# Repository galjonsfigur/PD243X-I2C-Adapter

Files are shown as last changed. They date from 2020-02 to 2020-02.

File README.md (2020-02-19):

# PD243X I²C Display Adapter Board

This repository contains KiCad design files, schematics and gerber files for a simple adapter board that allows to use old PD2435, PD2436 and PD2437 dot-matrix displays with most microcontrollers using I²C protocol instead of pin-consuming  parallel interface. They can be used as neat little displays for any project that requires some kind of simple and old-looking display.

## Photo (more in `images` folder)

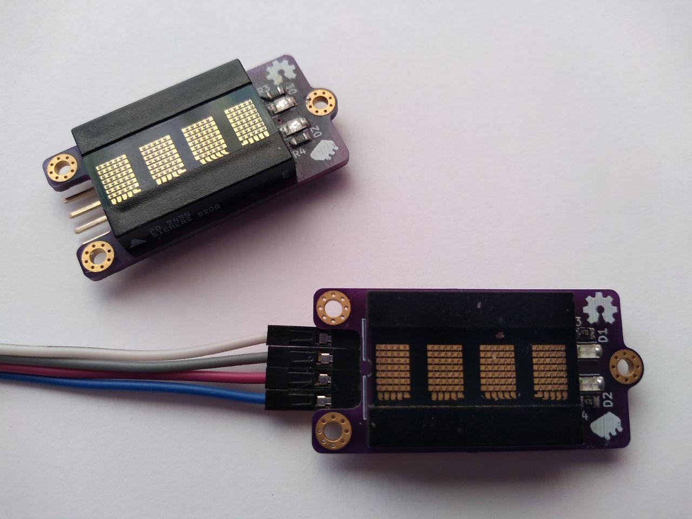
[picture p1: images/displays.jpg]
Display


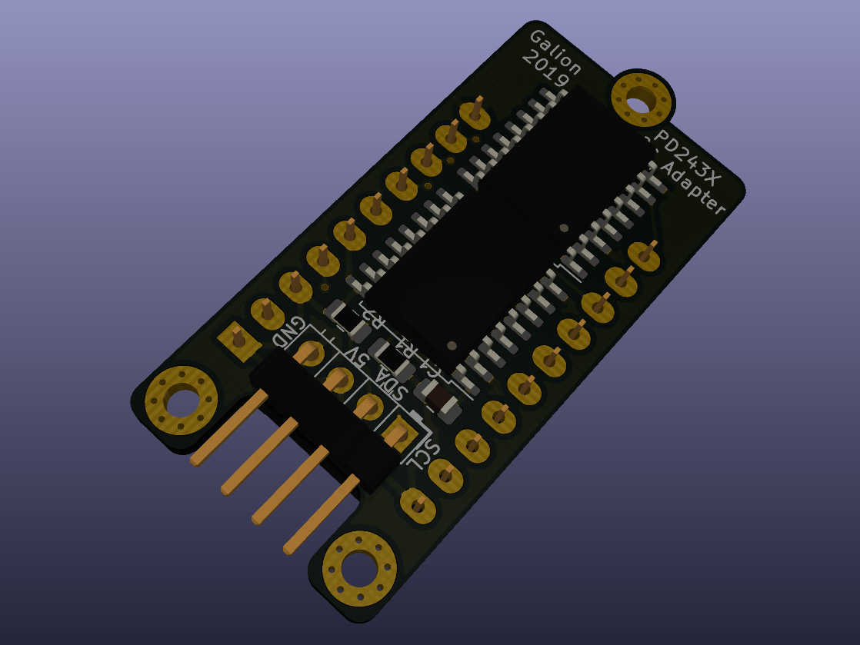
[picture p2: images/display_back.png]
3D view


## Details
PD245x displays are small four-digit alphanumeric dot-matrix displays. They use 8-bit data bus, 3-bit address line and additional signals to receive data from microcontroller. Because parallel interface requires many I/O pins to work, a simple I²C adapter board was designed. It uses 2 PCF8574T ICs to control all required pins of the display.

## Compatibility

This adapter board was designed with PD2435 in mind but it's working also with other color variants. According to the datasheet Also PD323X and PD443X displays can be used but probably they won't fit on this PCB as nicely as PD243X. 

## Bill of materials

- *1x*: PD243X display
- *1x*: 4 pin single row right angled header with 2.54mm pin spacing
- *2x*: PFC8574 I²C expander in SOIC-16 package
- *1x*: 100nF capacitor in 0805 SMD package
- *2x*: 4.7k ohm resisttor in 0805 SMD package
- *2x*: 470 ohm resisttor in 0805 SMD package
- *1x*: Green LED in 1206 SMD package
- *1x*: Red LED in 1206 SMD package

## License

[Solderpad Hardware Licence Version 2.0](LICENSE.md)

## Author
[Galion](galion$AT$sdf.org)

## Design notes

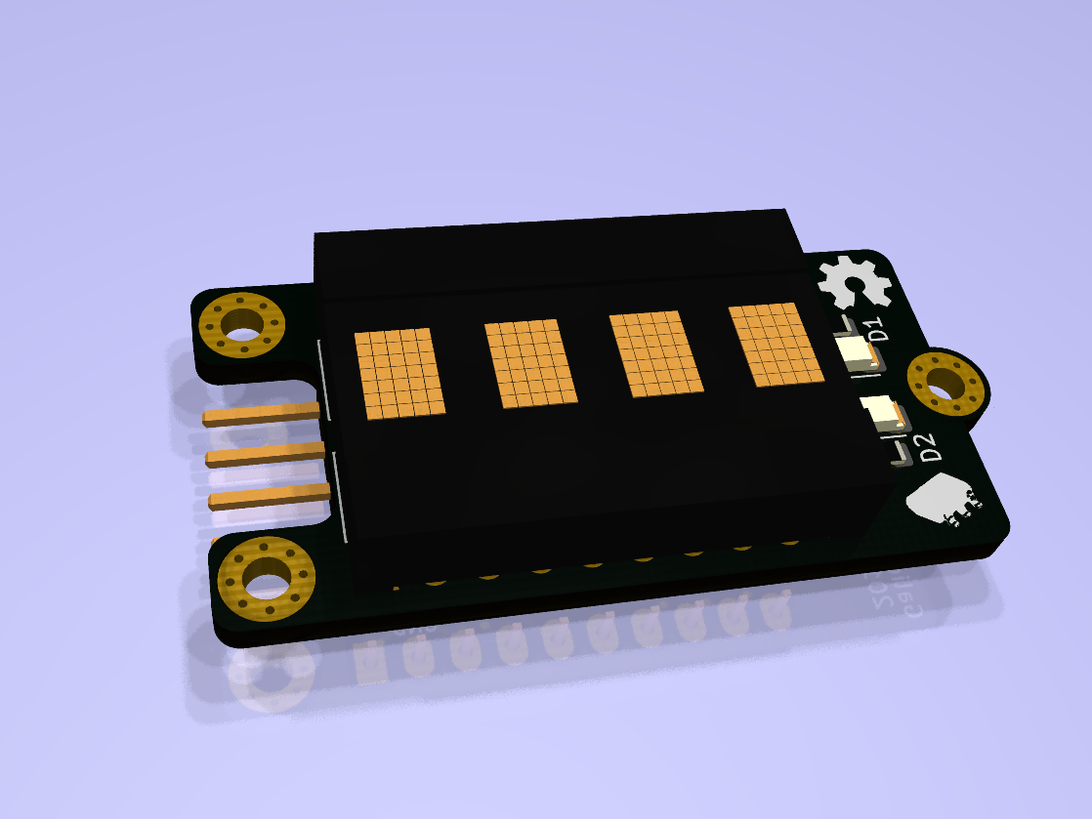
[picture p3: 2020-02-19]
images/display_front.png

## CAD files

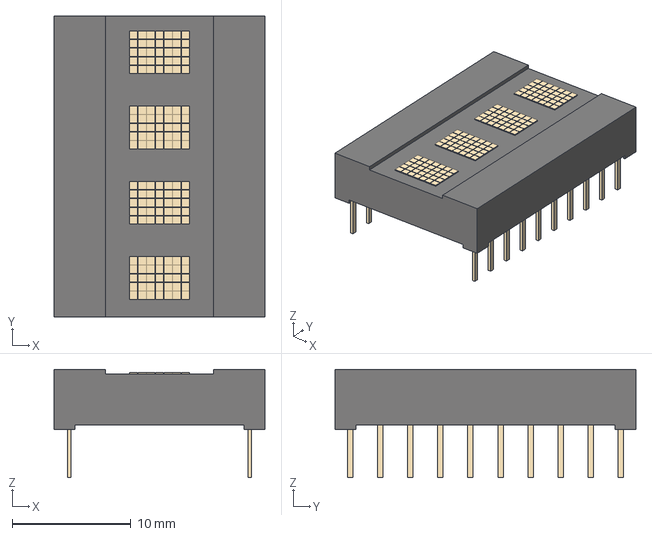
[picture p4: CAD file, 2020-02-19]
custom_symbols/PD2435.step
17.8 x 25.4 x 9.14 mm

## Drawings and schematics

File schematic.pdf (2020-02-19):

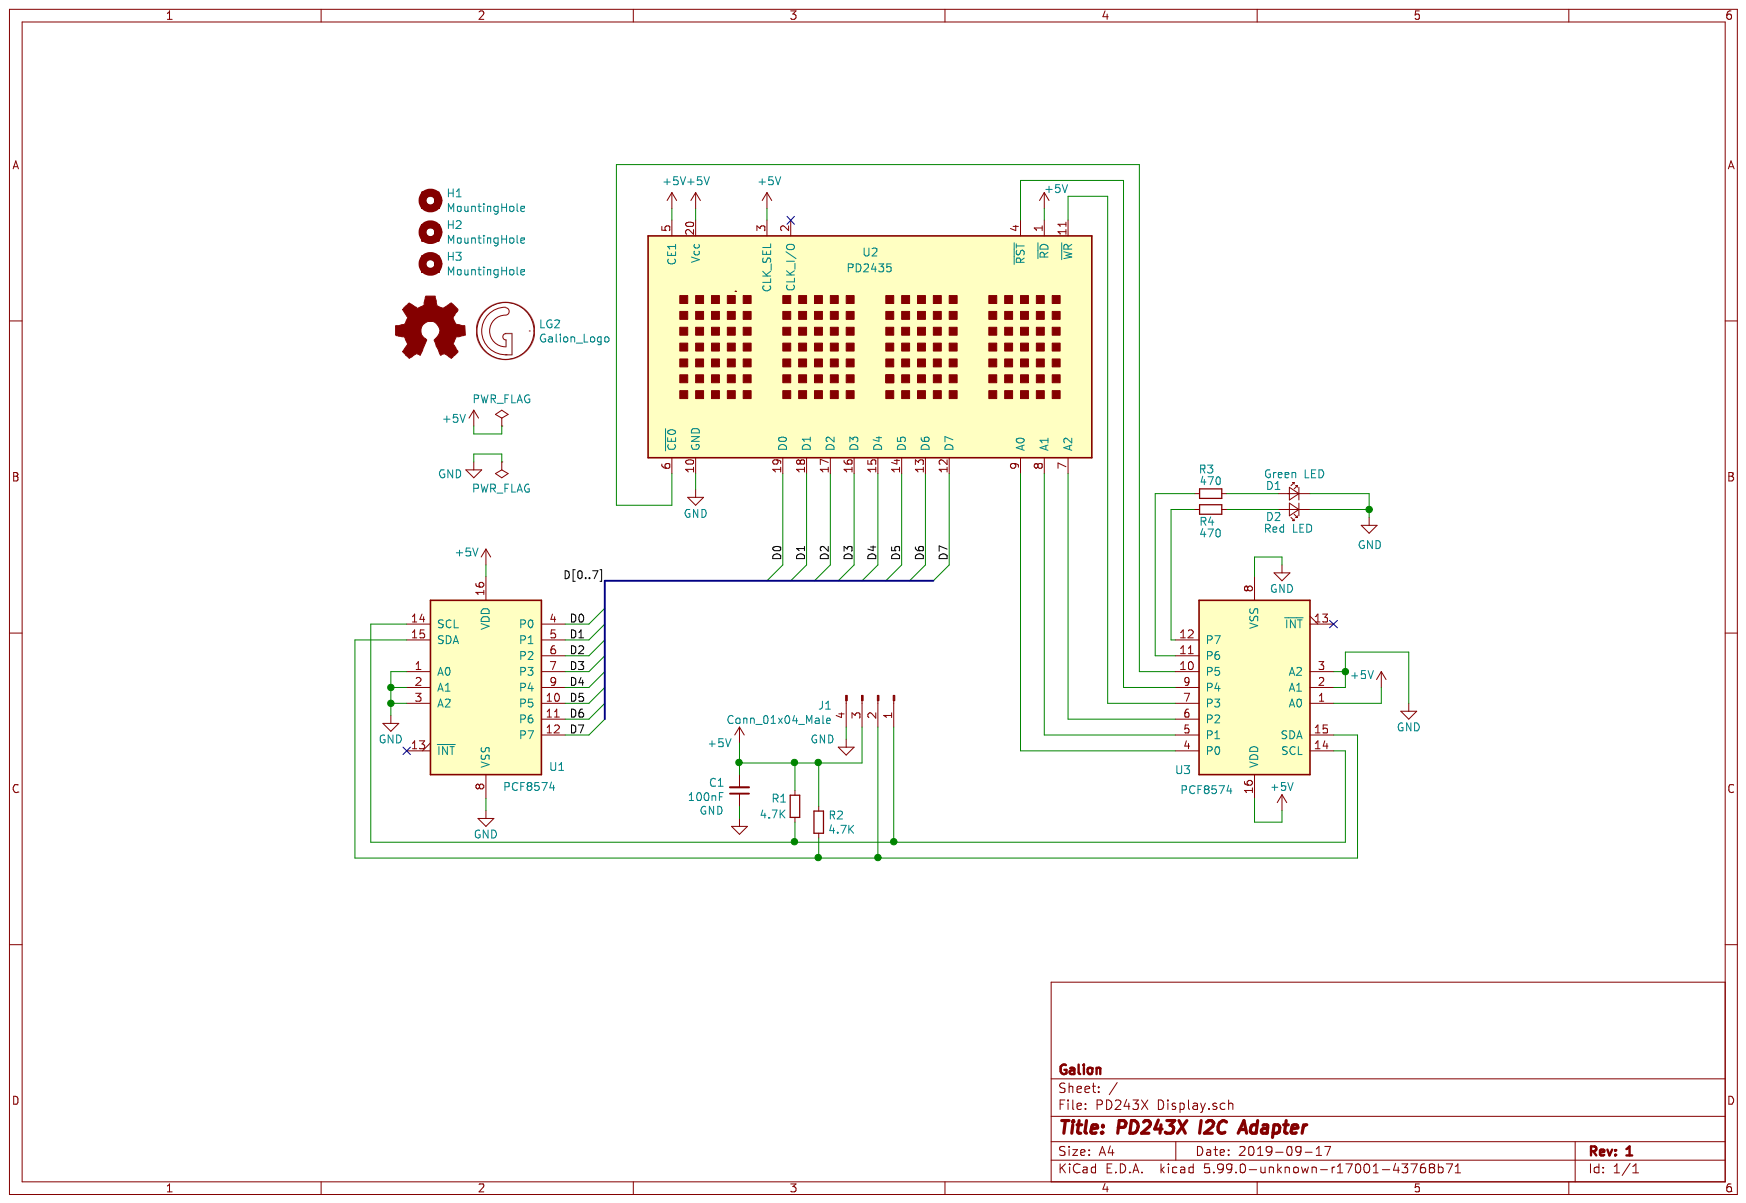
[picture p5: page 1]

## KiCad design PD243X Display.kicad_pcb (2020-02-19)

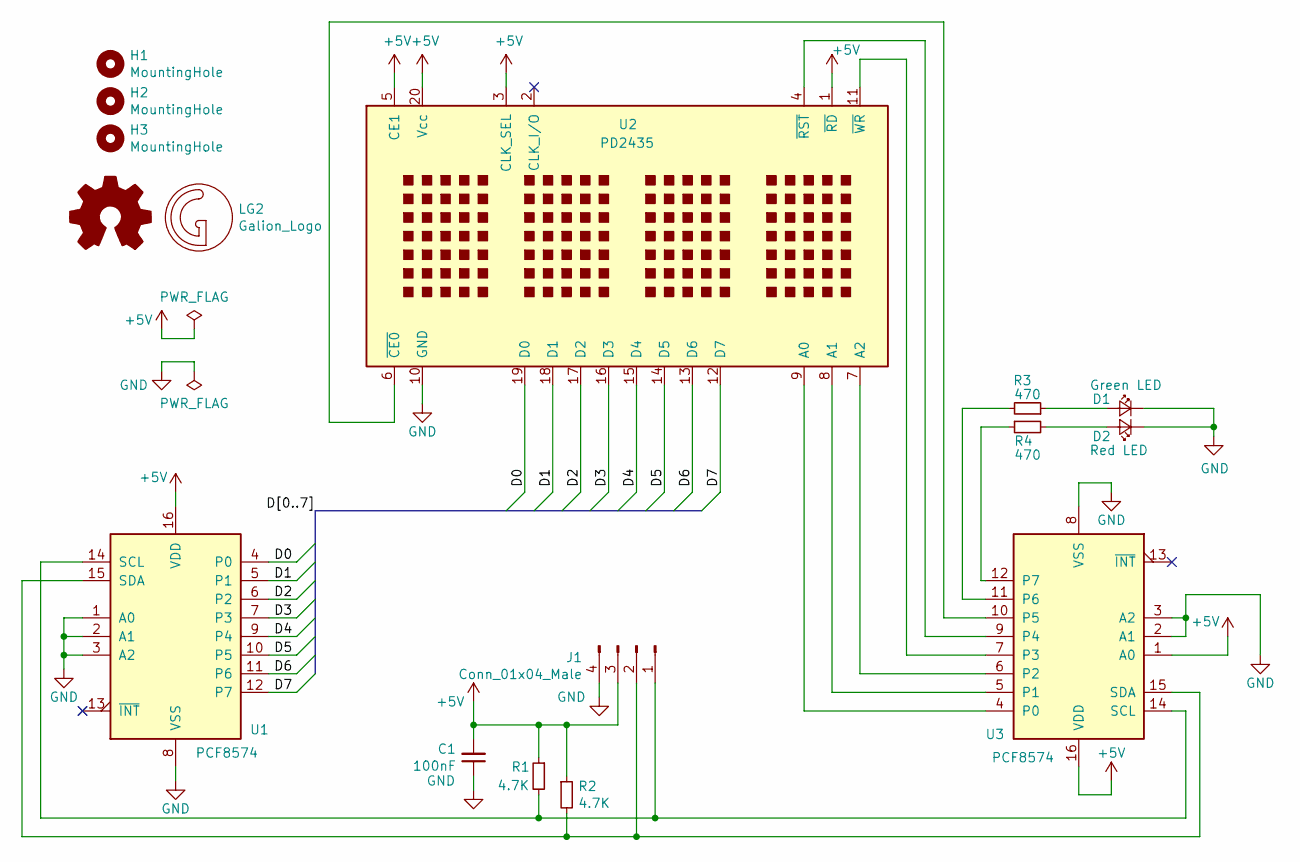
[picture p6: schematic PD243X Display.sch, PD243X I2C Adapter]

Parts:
C1: 100nF; C_0805_2012Metric_Pad1.15x1.40mm_HandSolder
D1: Green LED; LED_1206_3216Metric_Pad1.42x1.75mm_HandSolder
D2: Red LED; LED_1206_3216Metric_Pad1.42x1.75mm_HandSolder
H1, H2, H3: MountingHole; MountingHole_2.2mm_M2_Pad_Via
J1: Conn_01x04_Male; PinHeader_1x04_P2.54mm_Horizontal_cut
LG1: Logo_Open_Hardware_Small; OSHW-Symbol_5.7x6mm_SilkScreen
LG2: Galion_Logo; Galion_Logo_Small
R1, R2: 4.7K; R_0805_2012Metric_Pad1.15x1.40mm_HandSolder
R3, R4: 470; R_0805_2012Metric_Pad1.15x1.40mm_HandSolder
U1, U3: PCF8574; SOIC-16W_7.5x10.3mm_P1.27mm
U2: PD2435; DIP-20_W15.24mm_LongPads

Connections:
+5V: C1.2, J1.3, R1.1, R2.1, U1.16 (VDD), U2.1 (~RD), U2.3 (CLK_SEL), U2.5 (CE1), U2.20 (Vcc), U3.1 (A0), U3.16 (VDD)
/D0: U1.4 (P0), U2.19 (D0)
/D1: U1.5 (P1), U2.18 (D1)
/D2: U1.6 (P2), U2.17 (D2)
/D3: U1.7 (P3), U2.16 (D3)
/D4: U1.9 (P4), U2.15 (D4)
/D5: U1.10 (P5), U2.14 (D5)
/D6: U1.11 (P6), U2.13 (D6)
/D7: U1.12 (P7), U2.12 (D7)
GND: C1.1, D1.1 (K), D2.1 (K), J1.4, U1.1 (A0), U1.2 (A1), U1.3 (A2), U1.8 (VSS), U2.10 (GND), U3.2 (A1), U3.3 (A2), U3.8 (VSS)
unnamed: D1.2 (A), R3.1
unnamed: D2.2 (A), R4.2
unnamed: J1.1, R1.2, U1.14 (SCL), U3.14 (SCL)
unnamed: J1.2, R2.2, U1.15 (SDA), U3.15 (SDA)
unnamed: R3.2, U3.11 (P6)
unnamed: R4.1, U3.12 (P7)
unnamed: U2.4 (~RST), U3.9 (P4)
unnamed: U2.6 (~CE0), U3.10 (P5)
unnamed: U2.7 (A2), U3.6 (P2)
unnamed: U2.8 (A1), U3.5 (P1)
unnamed: U2.9 (A0), U3.4 (P0)
unnamed: U2.11 (~WR), U3.7 (P3)

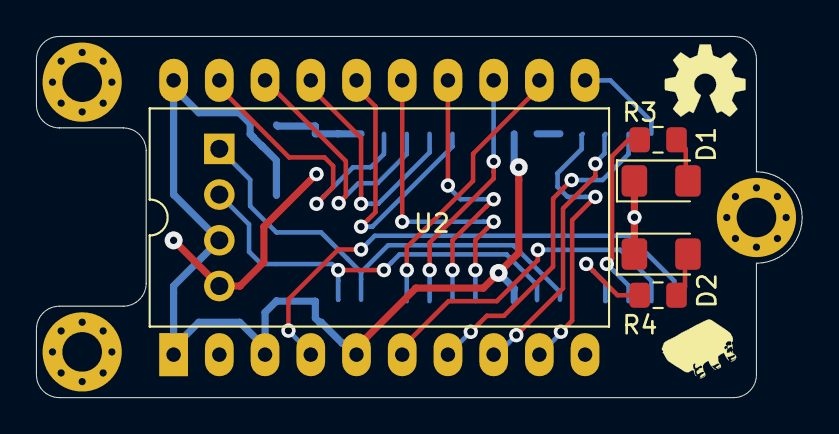
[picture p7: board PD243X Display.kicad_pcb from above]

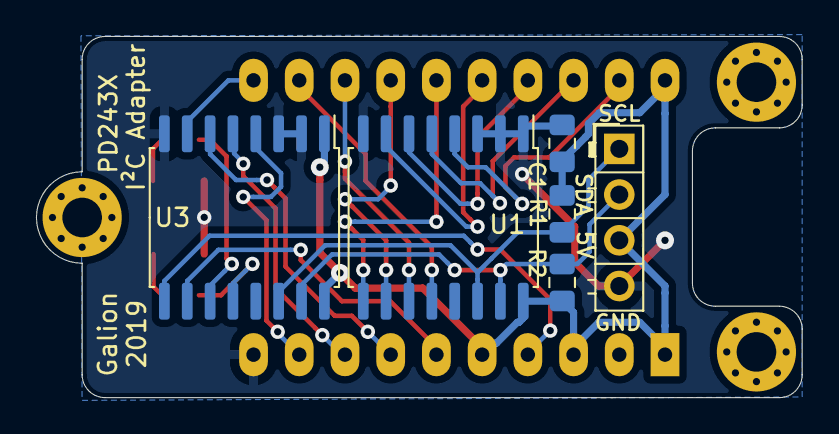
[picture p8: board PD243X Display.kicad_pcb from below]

Board: 2 copper layers, 42.5 x 20.1 mm, 16 parts (6 on the bottom side), 22 nets.
